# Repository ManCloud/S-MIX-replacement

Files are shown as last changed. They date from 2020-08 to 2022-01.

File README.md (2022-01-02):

# S-MIX-replacement

Replacement PCB for broken SNES S-MIX ICs and N64 AMP-NUS ICs

## Contributors
 * borti4938
   * he had the original idea of this board and helped a lot with the redesign.

## Changelog

v20210526
 * Moved to KiCad
 * changed overall layout
 * optimized to use single-layer
 
## Nice-to-know

During my investigations I found out, that the S-MIX of the SNES and the AMP-NUS of the N64 are functional identical.
I even swapped the chips between consoles and everything worked like a charm.

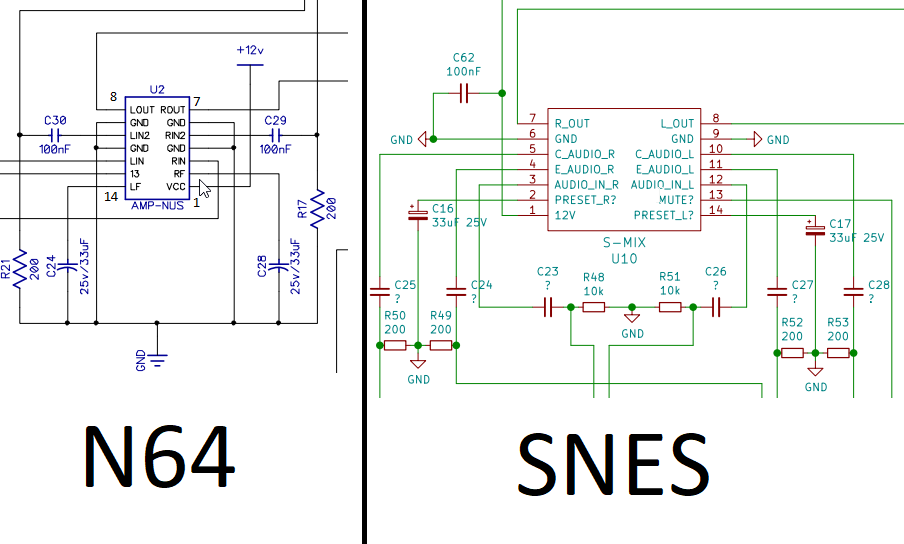
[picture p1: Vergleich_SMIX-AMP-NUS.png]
Comparison


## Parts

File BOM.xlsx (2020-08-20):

Qty | Value | Alternative | Package | Parts | Description
6 | 10k | - | R0805 | R3, R4, R5, R6, R7, R8 | RESISTOR, European symbol
1 | 10u | - | C1206 | C1 | CAPACITOR, European symbol
4 | 1k | - | R0805 | R9, R10, R15, R16 | RESISTOR, European symbol
2 | 1k8 | - | R0805 | R13, R14 | RESISTOR, European symbol
2 | 22k | 24k | R0805 | R11, R12 | RESISTOR, European symbol
2 | 33k | - | R0805 | R1, R2 | RESISTOR, European symbol
4 | BC846 | 2SC2412K | SOT23 | T1, T2, T3, T4 | NPN TRANSISTOR
1 | LM358D | - | SO08 | IC1 | OP AMP also LM158; LM258; LM2904

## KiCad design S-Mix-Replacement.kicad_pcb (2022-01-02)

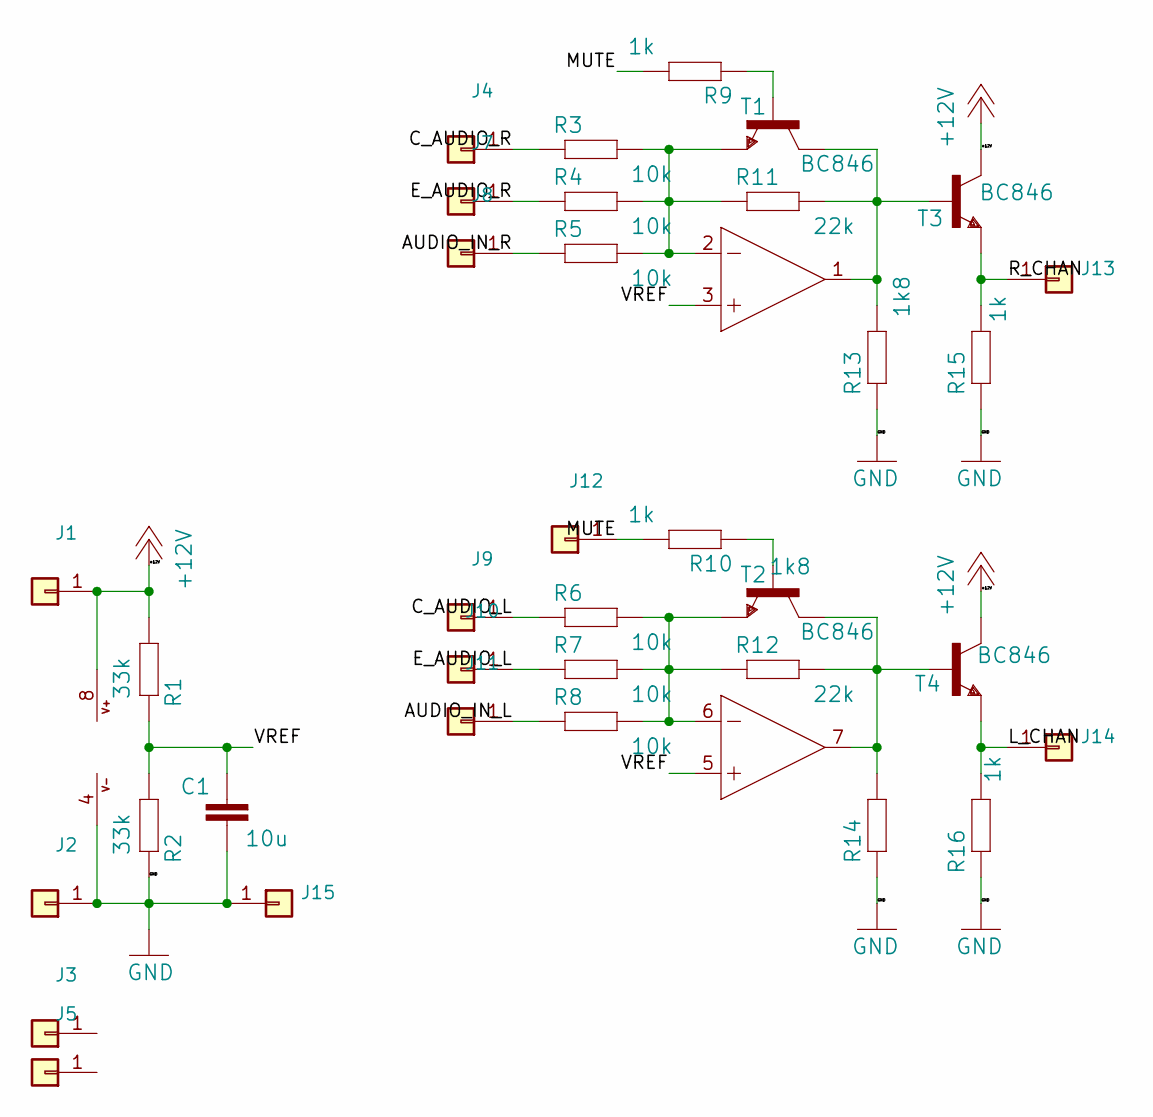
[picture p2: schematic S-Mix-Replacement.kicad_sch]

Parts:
C1: 10u; C_0805_2012Metric_Pad1.15x1.40mm_HandSolder
IC1: LM358D; SOIC-8_3.9x4.9mm_P1.27mm
J1, J2, J3, J4, J5, J7, J8, J9, J10, J11, J12, J13, J14, J15: TestPoint_THTPad_D1.0mm_Drill0.5mm
R1, R2: 33k; R_0603_1608Metric_Pad0.98x0.95mm_HandSolder
R3, R4, R5, R6, R7, R8: 10k; R_0603_1608Metric_Pad0.98x0.95mm_HandSolder
R9, R10, R15, R16: 1k; R_0603_1608Metric_Pad0.98x0.95mm_HandSolder
R11, R12: 22k; R_0603_1608Metric_Pad0.98x0.95mm_HandSolder
R13, R14: 1k8; R_0603_1608Metric_Pad0.98x0.95mm_HandSolder
T1, T2, T3, T4: BC846; SOT-23

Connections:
+12V: IC1.8 (V+), J1.1, R1.2, T3.3 (C), T4.3 (C)
/AUDIO_IN_L: J11.1, R8.1
/AUDIO_IN_R: J8.1, R5.1
/C_AUDIO_L: J9.1, R6.1
/C_AUDIO_R: J4.1, R3.1
/E_AUDIO_L: J10.1, R7.1
/E_AUDIO_R: J7.1, R4.1
/L_CHAN: J14.1, R16.2, T4.2 (E)
/MUTE: J12.1, R9.2, R10.2
/R_CHAN: J13.1, R15.2, T3.2 (E)
/VREF: C1.1, IC1.3 (+IN), IC1.5 (+IN), R1.1, R2.1
GND: C1.2, IC1.4 (V-), J2.1, J15.1, R2.2, R13.1, R14.1, R15.1, R16.1
unnamed: IC1.1 (OUT), R11.2, R13.2, T1.3 (C), T3.1 (B)
unnamed: IC1.2 (-IN), R3.2, R4.2, R5.2, R11.1, T1.2 (E)
unnamed: IC1.6 (-IN), R6.2, R7.2, R8.2, R12.1, T2.2 (E)
unnamed: IC1.7 (OUT), R12.2, R14.2, T2.3 (C), T4.1 (B)
unnamed: R9.1, T1.1 (B)
unnamed: R10.1, T2.1 (B)

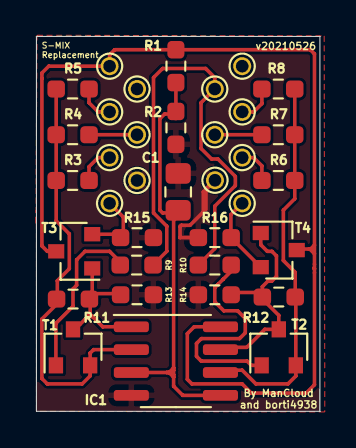
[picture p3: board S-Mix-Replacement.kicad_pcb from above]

Board: 2 copper layers, 15.7 x 20.8 mm, 36 parts (0 on the bottom side), 18 nets.

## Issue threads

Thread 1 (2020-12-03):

Request of the replace diagram

AlexHTP, 2020-12-03:
Hello,
I know the project have some issues as you say in the forum but with my null knowledge of german (i'm mexican) and the google translator i'm incapable of understand more than a few lines of those you wrote. I want try to fix my snes with your diagram and so i make you the kind request of it and if you can, i want to ask you for an explanation in english of the issue that made you desist from continue the project. I hope this isn't very intrusive or unrespectfull i only want to fix my snes.

ManCloud, 2020-12-05:
Hi ^^

The reason why I stopped working on this was simply that the console which needed it died completely because I forgot to discharge the capacitor at the psu.

There is one guy in the forum which already built the board based on the information here in github and except one thing (he says he has a little buzzing in the audio) it works as expected.

What diagramm exactly do you want me to put into english?

I'll do whatever I can to support you best .

Cya
ManCloud

Closed 2022-01-02.
